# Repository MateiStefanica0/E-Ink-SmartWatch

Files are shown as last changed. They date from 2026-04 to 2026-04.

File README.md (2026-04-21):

## 1. Schema bloc

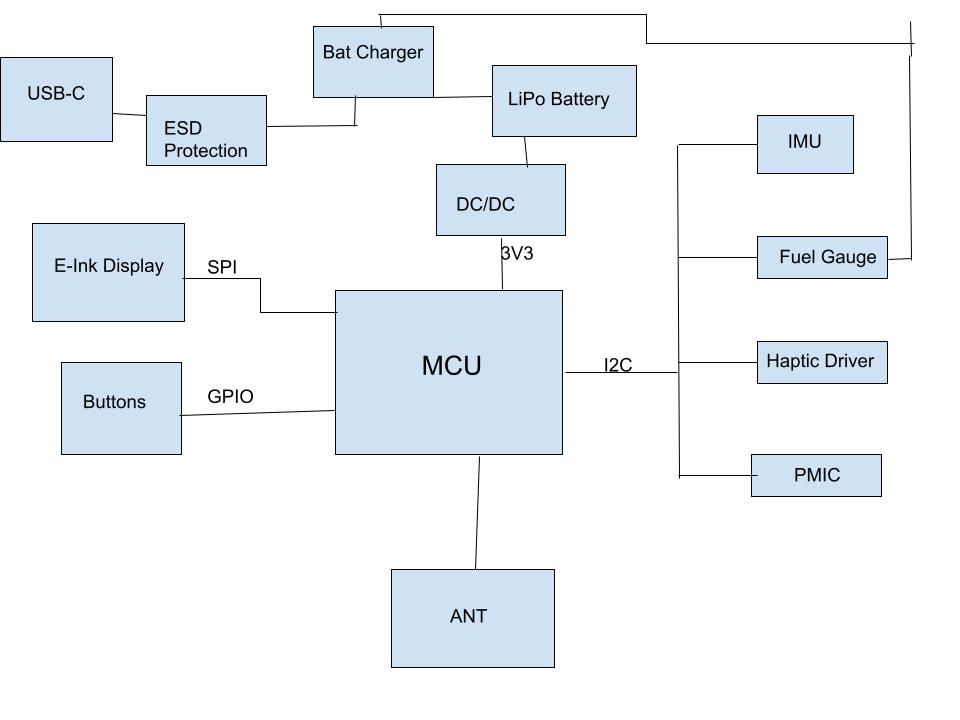
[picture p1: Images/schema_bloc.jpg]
Schema Bloc


## 2. Descrierea functionalitatii hardware

Sistemul este proiectat in jurul microcontrolerului nRF52840, punand accent pe conectivitate stabila si conservarea energiei, utilizand o tehnologie de afisare E-Paper care permite vizibilitate excelenta in lumina solara cu un consum de curent extrem de mic in starea statica.

### 2.1. Nucleul Sistemului (MCU)
* **Microcontroler:** Nordic nRF52840.
* **Comunicatie:** Gestioneaza functionalitatile Bluetooth si perifericele prin I2C si SPI.
* **Radio:** Semnalul trece printr-o retea de filtrare catre o antena ceramica de 2.4GHz. Sub antena, PCB-ul este decupat pentru a nu bloca semnalul.

### 2.2. Management Energie
* **Incarcare:** Chip-ul BQ25180 gestioneaza incarcarea bateriei LiPo prin mufa USB-C.
* **Monitorizare:** MAX17048 masoara constant nivelul bateriei si transmite datele prin I2C.
* **Regulator:** RT6160A (Buck-Boost) asigura o tensiune constanta de 3.3V, chiar si cand bateria se descarca.

### 2.3. Afisaj si Feedback
* **Ecran E-Paper:** Conectat prin interfata SPI pentru consum minim (consuma energie doar cand schimba imaginea).
* **Circuit Drive:** Include tranzistori si diode pentru a genera tensiunile necesare refresh-ului ecranului.
* **Vibratii:** Driver-ul DRV2605 controleaza motorul haptic, oferind alerte tactile utilizatorului.

### 2.4. Senzori si Protectie
* **Miscare:** Senzorul BMA423 (IMU) este folosit pentru pedometru si detectarea gestului de ridicare a mainii.
* **Protectie USB:** Chip-ul USBLC6-2 protejeaza placa impotriva descarcarilor electrostatice de pe portul USB.

### 2.5. Calcule de consum (estimativ)
* **Sleep Mode:** Consumul sistemului este de aproximativ 2-5 uA (nRF52840 + IMU in low power).
I_sleep = MCU_off + IMU_low + FuelGauge + DC/DC = 1.5 + 7 + 23 + 2 = ~33.5 uA
* **Active Mode:** In timpul transferului de date sau refresh-ului ecranului, consumul poate urca la 5-12 mA.
I_active = MCU_active + IMU_active + EPD_refresh + Haptic = ~10mAh
* **Autonomie:** 
Presupunand ca dintr-o ora, ceasul e activ 2 minute si in standby 58 de minute:
I_mediu = ( (I_active * 2 min) + (I_sleep * 58 min)) / 60 min = ~365 uA

Deci, autonomia e capacitatea_bateriei / I_mediu = 100mAh / 365uA = ~274 ore

## 3. Alocarea Pinilor nRF52840 (Pin Mapping)

Configuratia pinilor a fost aleasa pentru a optimiza rutarea pe PCB si pentru a respecta cerintele perifericelor. Toti pinii sunt configurati in firmware conform tabelului:

| Functie / Periferic | Semnal (Net) | Pin MCU | Explicatie |
| :--- | :--- | :--- | :--- |
| **I2C Bus (SCL)** | `I2C_SCL` | **P0.27** | Bus comun: IMU, Fuel Gauge, Haptic, PMIC. |
| **I2C Bus (SDA)** | `I2C_SDA` | **P0.26** | Bus comun: IMU, Fuel Gauge, Haptic, PMIC. |
| **SPI (SCK)** | `EPD_SCK` | **P0.31** | Ceas pentru transfer date catre ecran. |
| **SPI (MOSI)** | `EPD_MOSI` | **P0.29** | Date imagini catre ecran. |
| **EPD Control** | `EPD_BUSY` | **P0.05** | Indica daca ecranul este ocupat. |
| **EPD Control** | `EPD_RST` | **P0.06** | Reset hardware pentru ecran. |
| **EPD Control** | `EPD_DC` | **P0.08** | Selectie Date sau Comenzi (Data/Command). |
| **Butoane** | `SW_UP` | **P0.11** | Buton SUS (navigare). |
| **Butoane** | `SW_ENT` | **P0.12** | Buton SELECT (confirmare). |
| **Butoane** | `SW_DN` | **P0.14** | Buton JOS (navigare). |
| **Haptic Feedback**| `EN_HAPTIC` | **P0.17** | Activare driver vibratii. |
| **Senzor IMU** | `IMU_INT1` | **P0.19** | Intrerupere pentru detectare miscare. |
| **Debug/Prog** | `SWDIO` | `SWDIO` | Programare si depanare. |
| **Debug/Prog** | `SWCLK` | `SWCLK` | Ceas programare. |

---

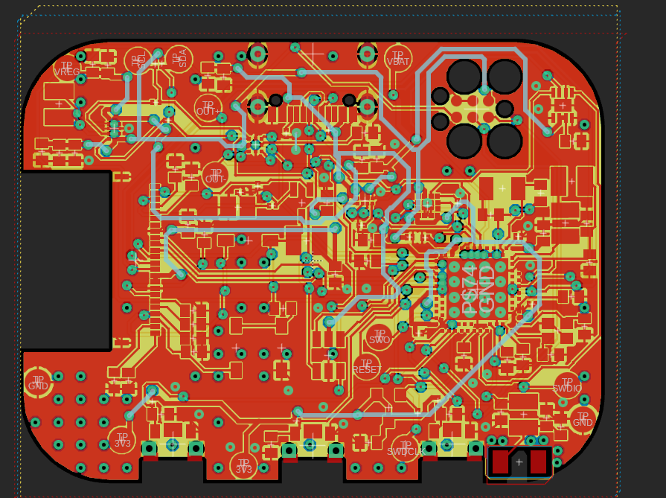
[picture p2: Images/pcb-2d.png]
PCB 2D

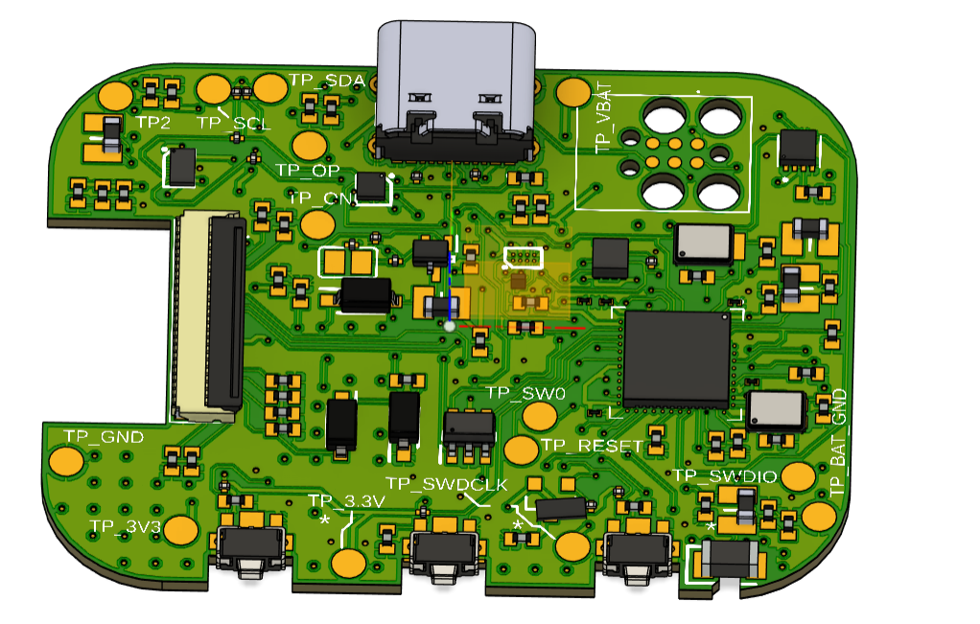
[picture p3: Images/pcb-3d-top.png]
PCB 3D-top

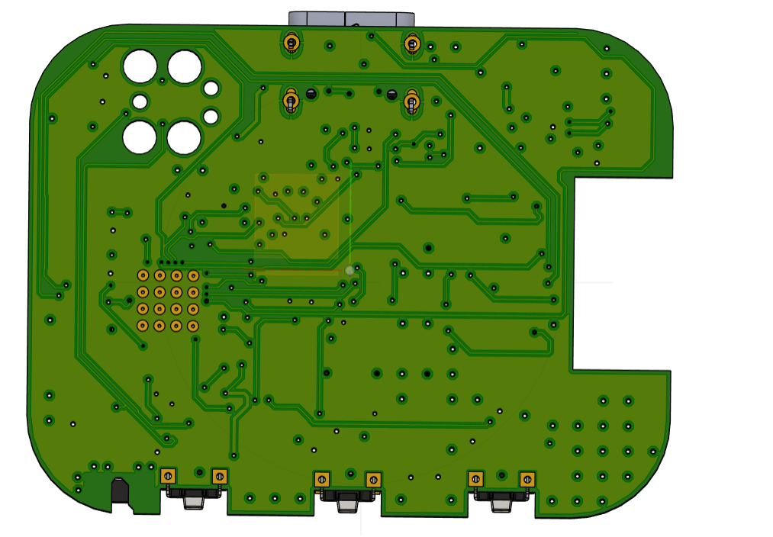
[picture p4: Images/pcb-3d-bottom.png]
PCB 3D-bottom

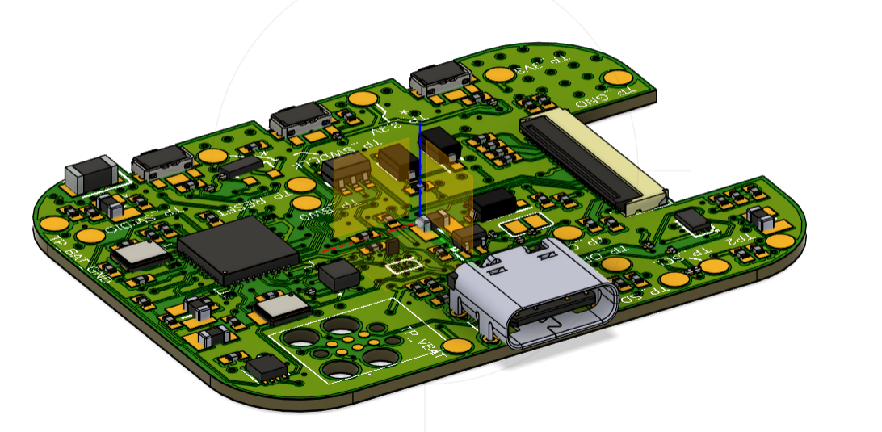
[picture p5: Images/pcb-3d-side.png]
PCB 3D-side

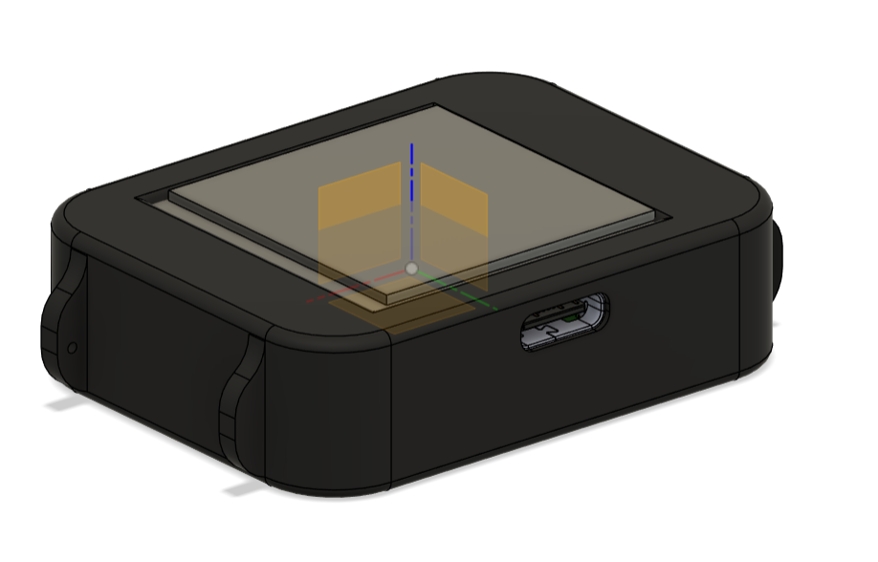
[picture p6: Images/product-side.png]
Carcasa-side

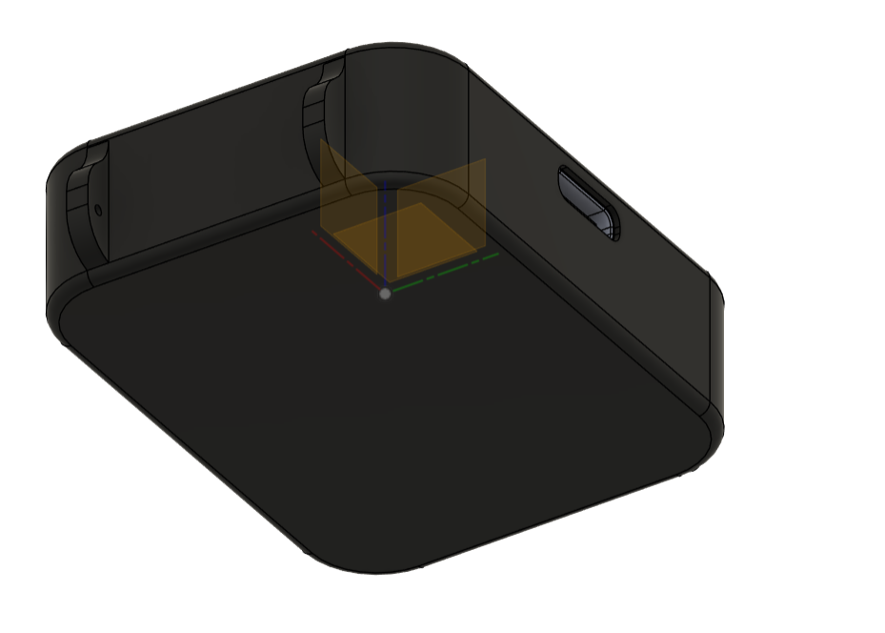
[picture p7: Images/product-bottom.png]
Carcasa-bottom


## 4. Detalii de Design (Design Log)

### 4.1. Implementare PCB
* **Antena RF:** Plasata pe margine, cu zona de sub ea libera (fara cupru) pentru semnal Bluetooth bun.
* **Grosime:** PCB-ul are 1.0mm grosime pentru a incapea in carcasa InkTime si am ales ca rutarea sa fie pe 4 layere: unul de GND, unul de Power, unul de top si unul de bottom.
* **Filtrare:** Condensatorii de 100nF sunt pusi cat mai aproape de pinii de alimentare ai chip-urilor.
* **Trasee:** Puterea are latime de 0.3mm, iar semnalele de date 0.15mm.
* **Abordare:** Initial, am incercat sa fac autorutare, dar nu a functionat, asa ca apoi am aranjat componentele pe placa pentru a fi cat mai putine fire intre pini indepartati, apoi am rutat semnalele care nu sunt de putere, apoi pe cele de putere, iar la final am pus polygon pour si am tras si ultimele fire de GND ramase.

### 4.2. Carcasa si Erori
* **Aliniere:** Butoanele si mufa USB-C sunt puse exact unde sunt gaurile in carcasa data.
* **Erori permise:** Erorile de tip "Dimension" de la USB si butoane sunt ignorate conform cerintelor proiectului. 
* **Erori ERC:** Singurele erori care au ramas sunt cele legate de pinii de care nu am legat nimic.
* **Erori DRC:** Erorile pe care le-am admis sunt cele cauzate de fire care trec printre alti pini ai microcontrollerului (asta nu se poate evita) sau viasuri care sunt prea apropiate din acelasi motiv.

## 5. Tabel BOM (Bill of Materials)

Mai jos sunt prezentate componentele principale necesare pentru asamblarea ceasului InkTime. Codurile de produs sunt optimizate pentru serviciul de asamblare JLC PCB.

| Designator | Componenta | Descriere / Parametri | Link Achizitie | Datasheet |
| :--- | :--- | :--- | :--- | :--- |
| U1 | **nRF52840** | MCU Bluetooth 5.4, ARM Cortex-M4F | [Link JLC](https://jlcpcb.com/partdetail/NordicSemicon-NRF52840_QIAAR/C190794) | [Datasheet](https://www.lcsc.com/datasheet/lcsc_datasheet_2304140030_Nordic-Semicon-NRF52840-QIAA-R_C190794.pdf) |
| U2 | **BQ25180YBGR** | IC Incarcare Baterie LiPo (I2C) | [Link JLC](https://jlcpcb.com/partdetail/TexasInstruments-BQ25180YBGR/C3682423) | [Datasheet](https://www.ti.com/cn/lit/gpn/bq25180) |
| U3 | **MAX17048G+T10**| Fuel Gauge (Monitorizare baterie) | [Link JLC](https://jlcpcb.com/partdetail/2777647-MAX17048GT10/C2682616) | [Datasheet](https://www.lcsc.com/datasheet/lcsc_datasheet_2410121738_Analog-Devices-Inc--Maxim-Integrated-MAX17048G-T10_C2682616.pdf) |
| IC1 | **RT6160AWSC** | Regulator Buck-Boost 3.3V | [Link JLC](https://jlcpcb.com/partdetail/RichtekTech-RT6160AWSC/C7065276) | [Datasheet](https://wmsc.lcsc.com/wmsc/upload/file/pdf/v2/lcsc/2312271436_Richtek-Tech-RT6160AWSC_C7065276.pdf) |
| IC2 | **BMA423** | Accelerometru 3 axe (IMU) | [Link JLC](https://jlcpcb.com/partdetail/BoschSensortec-BMA423/C189517) | [Datasheet](https://www.lcsc.com/datasheet/lcsc_datasheet_1810010040_Bosch-Sensortec-BMA423_C189517.pdf) |
| IC3 | **DRV2605YZFR** | Driver Motor Haptic (LRA/ERM) | [Link JLC](https://jlcpcb.com/partdetail/TexasInstruments-DRV2605YZFR/C81079) | [Datasheet](https://jlcpcb.com/partdetail/TexasInstruments-DRV2605YZFR/C81079) |
| ANT1 | **2450AT18B100E**| Antena Ceramica 2.4GHz | [Link JLC](https://jlcpcb.com/partdetail/JohansonDielectrics-2450AT18B100E/C2917717) | [Datasheet](https://www.lcsc.com/datasheet/lcsc_datasheet_2404021210_Johanson-Dielectrics-2450AT18B100E_C2917717.pdf) |
| J1 | **KH-TYPE-C-16P** | Conector USB Type-C 16 pini | [Link JLC](https://jlcpcb.com/partdetail/Shenzhen_KinghelmElec-KH_TYPE_C16P/C709357) | [Datasheet](https://jlcpcb.com/partdetail/Shenzhen_KinghelmElec-KH_TYPE_C16P/C709357) |
| J2 | **503480-2400** | Conector FPC 24 pini (E-Paper) | [Link JLC](https://jlcpcb.com/parts/componentSearch?searchTxt=503480-2400) | [Datasheet](https://www.molex.com/content/dam/molex/molex-dot-com/products/automated/en-us/salesdrawingpdf/503/503480/5034802400_sd.pdf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) |
| C_dec | **Condensator 100nF** | 0201, X5R, 6.3V (Decuplare generala) | [Link JLC](https://jlcpcb.com/partdetail/SamsungElectroMechanics-CL03A104KQ3NNNC/C1613) | [Datasheet](https://datasheet.lcsc.com/lcsc/1811141213_Samsung-Electro-Mechanics-CL03A104KQ3NNNC_C1613.pdf) |
| C_bulk | **Condensator 10uF** | 0402, X5R, 10V (Filtrare alimentare) | [Link JLC](https://jlcpcb.com/partdetail/MurataElectronics-GRM155R61A106ME11D/C155255) | [Datasheet](https://datasheet.lcsc.com/lcsc/1811011516_Murata-Electronics-GRM155R61A106ME11D_C155255.pdf) |
| R_pu | **Rezistenta 4.7k** | 0201, 1/20W (Pull-up I2C/Butoane) | [Link JLC](https://jlcpcb.com/partdetail/Yageo-RC0201JR074K7L/C13032) | [Datasheet](https://datasheet.lcsc.com/lcsc/1811021213_Yageo-RC0201JR-074K7L_C13032.pdf) |
| L_pwr | **Inductor 1.0uH** | 0805, 2.1A (Pentru RT6160A/Buck-Boost) | [Link JLC](https://jlcpcb.com/partdetail/Sunlord-MWSA0503S1R0MT/C2915000) | [Datasheet](https://datasheet.lcsc.com/lcsc/2203151500_Sunlord-MWSA0503S-1R0MT_C2915000.pdf) |
| X_32k | **Cristal 32.768kHz** | 1.6x1.0mm, 9pF (Pentru Sleep Mode nRF) | [Link JLC](https://jlcpcb.com/partdetail/YangzhouYangjieElectronic-FC1610AN32_7680KA_A/C147814) | [Datasheet](https://datasheet.lcsc.com/lcsc/1811141221_Epson-FC-1610-32-7680KA-A3_C147814.pdf) |
| D_esd | **USBLC6-2P6** | Protectie ESD USB (SOT-666) | [Link JLC](https://jlcpcb.com/partdetail/STMicroelectronics-USBLC62P6/C7519) | [Datasheet](https://www.st.com/resource/en/datasheet/usblc6-2.pdf) |

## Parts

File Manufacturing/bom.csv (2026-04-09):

Qty | Value | Device | Package | Parts | Description | ARROW_PART_NUMBER | ARROW_PRICE-STOCK | AVAILABILITY | CHECK_PRICES | COPYRIGHT | DESCRIPTION | DIGI-KEY_PART_NUMBER_1 | DIGI-KEY_PART_NUMBER_2 | DIGI-KEY_PART_NUMBER_3 | HEIGHT | JLCPCB | MANUFACTURER_NAME | MANUFACTURER_PART_NUMBER | MF | MOUSER_PART_NUMBER | MOUSER_PRICE-STOCK | MP | PACKAGE | POPULARITY | PRICE | PROD_ID | PURCHASE-URL | SNAPEDA_LINK | SPICEMODEL | SPICEPREFIX | TP_SIGNAL_NAME | VALUE
3 | 0 | ERA-1AEB3401C_CPF0201D7K68C1 | ERA-1AEB3401C_0201 | R2, R3, R4 | 7.68k 0201 Thin Film Surface Mount Fixed Resistor +/-0.5% 0.031W CPF0201D7K68C1
4 | 0.1uF | ESP32_C6_LIBRARY_1_ESP32_WROVER_EAGLE-LTSPICE_CC0402 | ESP32_C6_LIBRARY_1_ESP32_WROVER_EAGLE-LTSPICE_C0402 | C23, C27, C34, C42 | CAPACITOR, European symbol |  |  |  |  |  |  |  |  |  |  |  |  |  |  |  |  |  |  |  |  |  |  |  | NONE | C
1 | 0.1uF/50V | ESP32_C6_LIBRARY_1_ESP32_WROVER_EAGLE-LTSPICE_CC0402 | ESP32_C6_LIBRARY_1_ESP32_WROVER_EAGLE-LTSPICE_C0402 | EPD_C5 | CAPACITOR, European symbol |  |  |  |  |  |  |  |  |  |  |  |  |  |  |  |  |  |  |  |  |  |  |  | NONE | C
1 | 0.47 | ERA-1AEB3401C_CPF0201D7K68C1 | ERA-1AEB3401C_0201 | R1_EP_DR | 7.68k 0201 Thin Film Surface Mount Fixed Resistor +/-0.5% 0.031W CPF0201D7K68C1
5 | 100nF | NORDIC_NRF_3_CAPACITOR_0201_L | NORDIC_NRF_3_RESC0201_L | C5, C7, C8, C12, C19 | Generic chip capacitor
1 | 100pF | ESP32_C6_LIBRARY_1_ESP32_WROVER_EAGLE-LTSPICE_CC0402 | ESP32_C6_LIBRARY_1_ESP32_WROVER_EAGLE-LTSPICE_C0402 | C11 | CAPACITOR, European symbol |  |  |  |  |  |  |  |  |  |  |  |  |  |  |  |  |  |  |  |  |  |  |  | NONE | C
1 | 10K | ERA-1AEB3401C_CPF0201D7K68C1 | ERA-1AEB3401C_0201 | R2_EP_DR | 7.68k 0201 Thin Film Surface Mount Fixed Resistor +/-0.5% 0.031W CPF0201D7K68C1
1 | 10k | CPF0201D7K68C1_CPF0201D7K68C1 | CPF0201D7K68C1_0201 | R9 | 7.68k 0201 Thin Film Surface Mount Fixed Resistor +/-0.5% 0.031W CPF0201D7K68C1
4 | 10k | ERA-1AEB3401C_CPF0201D7K68C1 | ERA-1AEB3401C_0201 | R1, R5, R6, R_PWR_EPD | 7.68k 0201 Thin Film Surface Mount Fixed Resistor +/-0.5% 0.031W CPF0201D7K68C1
1 | 10nH | MLP2016SR47MT0S1_FTC252012SR47MBCA | MLP2016SR47MT0S1_INDC2016X100N | L3 | SMD / SMT Inductors (Coils), L=0.47?H, L x W x T : |  |  |  |  |  | SMD / SMT Inductors (Coils) | L=0.47?H | L x W x T : |  |  |  | 1mm | https://jlcpcb.com/partdetail/6763488-FTC252012SR47MBCA/C5832368 | TDK | FTC252012SR47MBCA
3 | 10uF | ESP32_C6_LIBRARY_1_ESP32_WROVER_EAGLE-LTSPICE_CC0402 | ESP32_C6_LIBRARY_1_ESP32_WROVER_EAGLE-LTSPICE_C0402 | C1-EP-DR, C24, C39 | CAPACITOR, European symbol |  |  |  |  |  |  |  |  |  |  |  |  |  |  |  |  |  |  |  |  |  |  |  | NONE | C
1 | 10uH | MLP2016SR47MT0S1_FTC252012SR47MBCA | MLP2016SR47MT0S1_INDC2016X100N | L2 | SMD / SMT Inductors (Coils), L=0.47?H, L x W x T : |  |  |  |  |  | SMD / SMT Inductors (Coils) | L=0.47?H | L x W x T : |  |  |  | 1mm | https://jlcpcb.com/partdetail/6763488-FTC252012SR47MBCA/C5832368 | TDK | FTC252012SR47MBCA
4 | 12pF | ESP32_C6_LIBRARY_1_ESP32_WROVER_EAGLE-LTSPICE_CC0402 | ESP32_C6_LIBRARY_1_ESP32_WROVER_EAGLE-LTSPICE_C0402 | C1, C2, C17, C18 | CAPACITOR, European symbol |  |  |  |  |  |  |  |  |  |  |  |  |  |  |  |  |  |  |  |  |  |  |  | NONE | C
2 | 1pF | ESP32_C6_LIBRARY_1_ESP32_WROVER_EAGLE-LTSPICE_CC0402 | ESP32_C6_LIBRARY_1_ESP32_WROVER_EAGLE-LTSPICE_C0402 | C3, C4 | CAPACITOR, European symbol |  |  |  |  |  |  |  |  |  |  |  |  |  |  |  |  |  |  |  |  |  |  |  | NONE | C
7 | 1uF | ESP32_C6_LIBRARY_1_ESP32_WROVER_EAGLE-LTSPICE_CC0402 | ESP32_C6_LIBRARY_1_ESP32_WROVER_EAGLE-LTSPICE_C0402 | C15, C29, C30, C31, C32, C37, C38 | CAPACITOR, European symbol |  |  |  |  |  |  |  |  |  |  |  |  |  |  |  |  |  |  |  |  |  |  |  | NONE | C
8 | 1uF/50V | ESP32_C6_LIBRARY_1_ESP32_WROVER_EAGLE-LTSPICE_CC0402 | ESP32_C6_LIBRARY_1_ESP32_WROVER_EAGLE-LTSPICE_C0402 | EPD_C2, EPD_C6, EPD_C7, EPD_C8, EPD_C9, EPD_C10, EPD_C11, EPD_C12 | CAPACITOR, European symbol |  |  |  |  |  |  |  |  |  |  |  |  |  |  |  |  |  |  |  |  |  |  |  | NONE | C
1 | 2.2 | ERA-1AEB3401C_CPF0201D7K68C1 | ERA-1AEB3401C_0201 | R_TYPE_SEL | 7.68k 0201 Thin Film Surface Mount Fixed Resistor +/-0.5% 0.031W CPF0201D7K68C1
3 | 2025-10-22_07-23-44_LIBRARY_EVP-AKE31ASW_EVP-AKE31A_PAN | 2025-10-22_07-23-44_LIBRARY_EVP-AKE31ASW_EVP-AKE31A_PAN | 2025-10-22_07-23-44_LIBRARY_SW_EVP-AKE31A_PAN | SW1, SW2, SW3 |  |  |  |  |  | Copyright (C) 2025 Ultra Librarian. All rights reserved. |  | P123437TR-ND | P123437CT-ND | P123437DKR-ND |  |  | Panasonic | EVP-AKE31A
1 | 20V/4.2A/52mO/1.4W | ESP32_C6_LIBRARY_4_ESP32_WROVER_SPARKFUN-DISCRETESEMI_MOSFET_PCH-DMG2305UX-7 | ESP32_C6_LIBRARY_4_ESP32_C6_LIBRARY_4_ESP32_C6_LIBRARY_4_ESP32_C6_LIBRARY_4_ESP32_WROVER_SPARKFUN-DISCRETESEMI_SOT23-3 | Q1 | P-channel MOSFETs |  |  |  |  |  |  |  |  |  |  |  |  |  |  |  |  |  |  |  |  | TRAN-14388 |  |  |  |  |  | 20V/4.2A/52mO/1.4W
2 | 22uF | ESP32_C6_LIBRARY_1_ESP32_WROVER_EAGLE-LTSPICE_CC0402 | ESP32_C6_LIBRARY_1_ESP32_WROVER_EAGLE-LTSPICE_C0402 | C25, C33 | CAPACITOR, European symbol |  |  |  |  |  |  |  |  |  |  |  |  |  |  |  |  |  |  |  |  |  |  |  | NONE | C
1 | 2450AT18B100E_2450AT18B100E | 2450AT18B100E_2450AT18B100E | 2450AT18B100E_ANTC3216X140N | ANT1 | Antennas 2.45GHz ANTENNA | 2450AT18B100E | https://www.arrow.com/en/products/2450at18b100e/johanson-dielectrics?utm_currency=USD&region=nac |  |  |  | Antennas 2.45GHz ANTENNA |  |  |  | 1.4mm |  | JOHANSON TECHNOLOGY | 2450AT18B100E |  | 609-2450AT18B100E | https://www.mouser.co.uk/ProductDetail/Johanson-Technology/2450AT18B100E?qs=yCnrNFeXz%252Bh5MFsFIXGZGA%3D%3D
1 | 3.9nH | MLP2016SR47MT0S1_FTC252012SR47MBCA | MLP2016SR47MT0S1_INDC2016X100N | L1 | SMD / SMT Inductors (Coils), L=0.47?H, L x W x T : |  |  |  |  |  | SMD / SMT Inductors (Coils) | L=0.47?H | L x W x T : |  |  |  | 1mm | https://jlcpcb.com/partdetail/6763488-FTC252012SR47MBCA/C5832368 | TDK | FTC252012SR47MBCA
1 | 32.768kHz | NORDIC_NRF_1_XTAL_32KHZ | NORDIC_NRF_1_XTAL_3215_N | X2
1 | 32MHz | NORDIC_NRF_XTAL_32MHZ | NORDIC_NRF_BT-XTAL_2016_N | X1
2 | 3k3 | ERA-1AEB3401C_CPF0201D7K68C1 | ERA-1AEB3401C_0201 | R17, R18 | 7.68k 0201 Thin Film Surface Mount Fixed Resistor +/-0.5% 0.031W CPF0201D7K68C1
5 | 4.7uF | ESP32_C6_LIBRARY_1_ESP32_WROVER_EAGLE-LTSPICE_CC0402 | ESP32_C6_LIBRARY_1_ESP32_WROVER_EAGLE-LTSPICE_C0402 | C6, C14, C20, C21, C43 | CAPACITOR, European symbol |  |  |  |  |  |  |  |  |  |  |  |  |  |  |  |  |  |  |  |  |  |  |  | NONE | C
1 | 4.7uF/25V | ESP32_C6_LIBRARY_1_ESP32_WROVER_EAGLE-LTSPICE_CC0402 | ESP32_C6_LIBRARY_1_ESP32_WROVER_EAGLE-LTSPICE_C0402 | C2-EP-DR | CAPACITOR, European symbol |  |  |  |  |  |  |  |  |  |  |  |  |  |  |  |  |  |  |  |  |  |  |  | NONE | C
1 | 47nF | ESP32_C6_LIBRARY_1_ESP32_WROVER_EAGLE-LTSPICE_CC0402 | ESP32_C6_LIBRARY_1_ESP32_WROVER_EAGLE-LTSPICE_C0402 | C16 | CAPACITOR, European symbol |  |  |  |  |  |  |  |  |  |  |  |  |  |  |  |  |  |  |  |  |  |  |  | NONE | C
1 | 503480-2400_503480-2400 | 503480-2400_503480-2400 | 503480-2400_5034802400 | J2 | FFC & FPC Connectors 0.5mm FPC RA SMT Dual Contact 24Ckt |  |  |  |  |  | FFC & FPC Connectors 0.5mm FPC RA SMT Dual Contact 24Ckt |  |  |  | 1.87mm |  | Molex | 503480-2400 |  | 538-503480-2400 | https://www.mouser.co.uk/ProductDetail/Molex/503480-2400?qs=OAhjpuo3Vu7efIoxFh9AOw%3D%3D
2 | 5k1 | ERA-1AEB3401C_CPF0201D7K68C1 | ERA-1AEB3401C_0201 | R1_USB, R2_USB | 7.68k 0201 Thin Film Surface Mount Fixed Resistor +/-0.5% 0.031W CPF0201D7K68C1
1 | 68uH | MLP2016SR47MT0S1_FTC252012SR47MBCA | MLP2016SR47MT0S1_INDC2016X100N | L5 | SMD / SMT Inductors (Coils), L=0.47?H, L x W x T : |  |  |  |  |  | SMD / SMT Inductors (Coils) | L=0.47?H | L x W x T : |  |  |  | 1mm | https://jlcpcb.com/partdetail/6763488-FTC252012SR47MBCA/C5832368 | TDK | FTC252012SR47MBCA
1 | 820pF | ESP32_C6_LIBRARY_1_ESP32_WROVER_EAGLE-LTSPICE_CC0402 | ESP32_C6_LIBRARY_1_ESP32_WROVER_EAGLE-LTSPICE_C0402 | C9 | CAPACITOR, European symbol |  |  |  |  |  |  |  |  |  |  |  |  |  |  |  |  |  |  |  |  |  |  |  | NONE | C
1 | BMA423_BMA423 | BMA423_BMA423 | BMA423_BMA423 | IC3 | Accelerometers Triaxial low-g 12bit Acceleration Sensor | BMA423 | https://www.arrow.com/en/products/bma423/bosch |  |  |  | Accelerometers Triaxial low-g 12bit Acceleration Sensor |  |  |  | 1mm |  | BOSCH | BMA423 |  | 262-BMA423 | https://www.mouser.co.uk/ProductDetail/Bosch-Sensortec/BMA423?qs=HXFqYaX1Q2xC%252BSgeGoX3mg%3D%3D
1 | BQ25180YBGR_BQ25180YBGR | BQ25180YBGR_BQ25180YBGR | BQ25180YBGR_BGA8C40P2X4_100X155X50 | IC1 | Charger IC Lithium Ion/Polymer, Lithium Iron Phosphate 8-DSBGA (1.6x1.1) | BQ25180YBGR | https://www.arrow.com/en/products/bq25180ybgr/texas-instruments?utm_currency=USD&region=nac |  |  |  | Charger IC Lithium Ion/Polymer | Lithium Iron Phosphate 8-DSBGA (1.6x1.1) |  |  |  | 0.5mm |  | Texas Instruments | BQ25180YBGR |  | 595-BQ25180YBGR | https://www.mouser.co.uk/ProductDetail/Texas-Instruments/BQ25180YBGR?qs=doiCPypUmgEWjAK%252BJAX6Tw%3D%3D
1 | DRV2605YZFR_DRV2605YZFR | DRV2605YZFR_DRV2605YZFR | DRV2605YZFR_BGA9C50P3X3_144X144X62 | IC4 | Haptic Driver for ERM/LRA with Built-In Library and Smart Loop Architecture | DRV2605YZFR | https://www.arrow.com/en/products/drv2605yzfr/texas-instruments?region=nac |  |  |  | Haptic Driver for ERM/LRA with Built-In Library and Smart Loop Architecture |  |  |  | 0.625mm |  | Texas Instruments | DRV2605YZFR
1 | ESP32_C6_LIBRARY_3_USBLC6-2SC6Y | ESP32_C6_LIBRARY_3_USBLC6-2SC6Y | ESP32_C6_LIBRARY_3_SOT95P280X145-6N | D1 | Low Cap. ESD Protection Auto SOT-23-6 STMicroelectronics USBLC6-2SC6Y, Dual Uni-Directional TVS Diode Array, 6-Pin SOT-23 |  |  | In Stock | https://www.snapeda.com/parts/USBLC6-2SC6Y/STMicroelectronics/view-part/?ref=eda |  | 17V Clamp 5A (8/20µs) Ipp Tvs Diode Surface Mount SOT-23-6 |  |  |  |  |  |  |  | STMicroelectronics |  |  | USBLC6-2SC6Y | SOT-23-6 STMicroelectronics |  | None |  |  | https://www.snapeda.com/parts/USBLC6-2SC6Y/STMicroelectronics/view-part/?ref=snap
1 | ESP32_C6_LIBRARY_6_SI1308EDL-T1-GE3 | ESP32_C6_LIBRARY_6_SI1308EDL-T1-GE3 | ESP32_C6_LIBRARY_6_SOT65P210X110-3N | Q3 | MOSFET N-Ch 30V 1.5A TrenchFET SC70 Vishay Si1308EDL-T1-GE3 N-channel MOSFET Transistor, 1.5 A, 30 V, 3-Pin SC-70 |  |  | In Stock | https://www.snapeda.com/parts/SI1308EDL-T1-GE3/Vishay+Siliconix/view-part/?ref=eda |  | Si1308EDL-T1-GE3 N-channel MOSFET Transistor | 1.5 A | 30 V | 3-Pin SC-70 | Siliconix / Vishay SI1308EDL-T1-GE3 |  |  |  |  |  |  |  | Vishay Siliconix |  |  | SI1308EDL-T1-GE3 | SOT-323 Vishay Semiconductor |  | None |  | https://www.snapeda.com/api/url_track_click_mouser/?unipart_id=274603&manufacturer=Vishay Siliconix&part_name=SI1308EDL-T1-GE3&search_term=None | https://www.snapeda.com/parts/SI1308EDL-T1-GE3/Vishay+Siliconix/view-part/?ref=snap
1 | ESP32_C6_LIBRARY_MAX17048G+T10 | ESP32_C6_LIBRARY_MAX17048G+T10 | ESP32_C6_LIBRARY_SON50P200X200X80-9N | U1 | Check availability |  |  | In Stock | https://www.snapeda.com/parts/MAX17048G+T10/Analog+Devices/view-part/?ref=eda |  | 3µA 1-Cell/2-Cell Fuel Gauge with ModelGauge |  |  |  |  |  |  |  | Analog Devices |  |  | MAX17048G+T10 | TDFN-8 Maxim |  | None |  | https://www.snapeda.com/api/url_track_click_mouser/?unipart_id=329239&manufacturer=Analog Devices&part_name=MAX17048G+T10&search_term=None | https://www.snapeda.com/parts/MAX17048G+T10/Analog+Devices/view-part/?ref=snap
14 | HECTOR_WATCH_1_TPTP20R | HECTOR_WATCH_1_TPTP20R | HECTOR_WATCH_1_TP20R | TP2, TP_3.3V, TP_3V3, TP_BAT_GND, TP_GND, TP_ON, TP_OP, TP_RESET, TP_SCL, TP_SDA, TP_SW0, TP_SWDCLK, TP_SWDIO, TP_VBAT | Test pad |  |  |  |  |  |  |  |  |  |  |  |  |  |  |  |  |  |  | 2
1 | KH-TYPE-C-16P_KH-TYPE-C-16P | KH-TYPE-C-16P_KH-TYPE-C-16P | KH-TYPE-C-16P_KINGHELM_KH-TYPE-C-16P | J3 | Check availability |  |  | Not in stock | https://www.snapeda.com/parts/KH-TYPE-C-16P/Kinghelm/view-part/?ref=eda |  |  |  |  |  |  |  |  |  | kinghelm |  |  | KH-TYPE-C-16P | None |  | None |  |  | https://www.snapeda.com/parts/KH-TYPE-C-16P/Kinghelm/view-part/?ref=snap
3 | MBR0503 | ESP32_C6_LIBRARY_5_MBR0530 | ESP32_C6_LIBRARY_5_SOD3716X135N | D2, D4, D5 | ON SEMICONDUCTOR - MBR0530 - DIODE, SCHOTTKY, 0.5A, 30V, SOD-123 |  |  | In Stock | https://www.snapeda.com/parts/MBR0530/Onsemi/view-part/?ref=eda |  | Diode Schottky 30 V 500mA Surface Mount SOD-123 |  |  |  |  |  |  |  | ON Semiconductor |  |  | MBR0530 | SOD-123-2 ON Semiconductor |  | None |  | https://www.snapeda.com/api/url_track_click_mouser/?unipart_id=179458&manufacturer=ON Semiconductor&part_name=MBR0530&search_term=None | https://www.snapeda.com/parts/MBR0530/Onsemi/view-part/?ref=snap
1 | MLP2016SR47MT0S1_FTC252012SR47MBCA | MLP2016SR47MT0S1_FTC252012SR47MBCA | MLP2016SR47MT0S1_INDC2016X100N | L7 | SMD / SMT Inductors (Coils), L=0.47?H, L x W x T : |  |  |  |  |  | SMD / SMT Inductors (Coils) | L=0.47?H | L x W x T : |  |  |  | 1mm | https://jlcpcb.com/partdetail/6763488-FTC252012SR47MBCA/C5832368 | TDK | FTC252012SR47MBCA
3 | N.C. | ESP32_C6_LIBRARY_1_ESP32_WROVER_EAGLE-LTSPICE_CC0402 | ESP32_C6_LIBRARY_1_ESP32_WROVER_EAGLE-LTSPICE_C0402 | C10, C13, C22 | CAPACITOR, European symbol |  |  |  |  |  |  |  |  |  |  |  |  |  |  |  |  |  |  |  |  |  |  |  | NONE | C
1 | NORDIC_NRF_4_NRF52840_QF | NORDIC_NRF_4_NRF52840_QF | NORDIC_NRF_4_AQFN50P700X700X85_HS-74N | U$1 | nRF52840
1 | RT6160AWSC_RT6160AWSC | RT6160AWSC_RT6160AWSC | RT6160AWSC_BGA15C40P3X5_140X230X60 | IC2 | Buck-Boost Regulator Positive Output Step-Up/Step-Down I2C DC-DC Controller IC 15-WL-CSP (BSC) (1.4x2.3) |  |  |  |  |  | Buck-Boost Regulator Positive Output Step-Up/Step-Down I2C DC-DC Controller IC 15-WL-CSP (BSC) (1.4x2.3) |  |  |  | 0.6mm |  | RICHTEK | RT6160AWSC |  | 835-RT6160AWSC | https://www.mouser.co.uk/ProductDetail/Richtek/RT6160AWSC?qs=amGC7iS6iy%2FLd9PSoixZXQ%3D%3D
1 | SJ | ESP32_C6_LIBRARY_7_JUMPER_SJ | ESP32_C6_LIBRARY_7_JUMPER_SJ | SJ1 | SMD solder JUMPER |  |  |  |  |  |  |  |  |  |  |  |  |  |  |  |  |  |  | 3
1 | TC2030-IDC_TC2030-IDC | TC2030-IDC_TC2030-IDC | TC2030-IDC_TC2030IDC | J1 | CABLE ADAPTER 6 POS |  |  |  |  |  | CABLE ADAPTER 6 POS |  |  |  | 19mm |  | Tag Connect | TC2030-IDC
1 | iuF/50V | ESP32_C6_LIBRARY_1_ESP32_WROVER_EAGLE-LTSPICE_CC0402 | ESP32_C6_LIBRARY_1_ESP32_WROVER_EAGLE-LTSPICE_C0402 | EPD_C1 | CAPACITOR, European symbol |  |  |  |  |  |  |  |  |  |  |  |  |  |  |  |  |  |  |  |  |  |  |  | NONE | C

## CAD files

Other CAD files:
Mechanical/proiect_tsc-pcb3D.f3z

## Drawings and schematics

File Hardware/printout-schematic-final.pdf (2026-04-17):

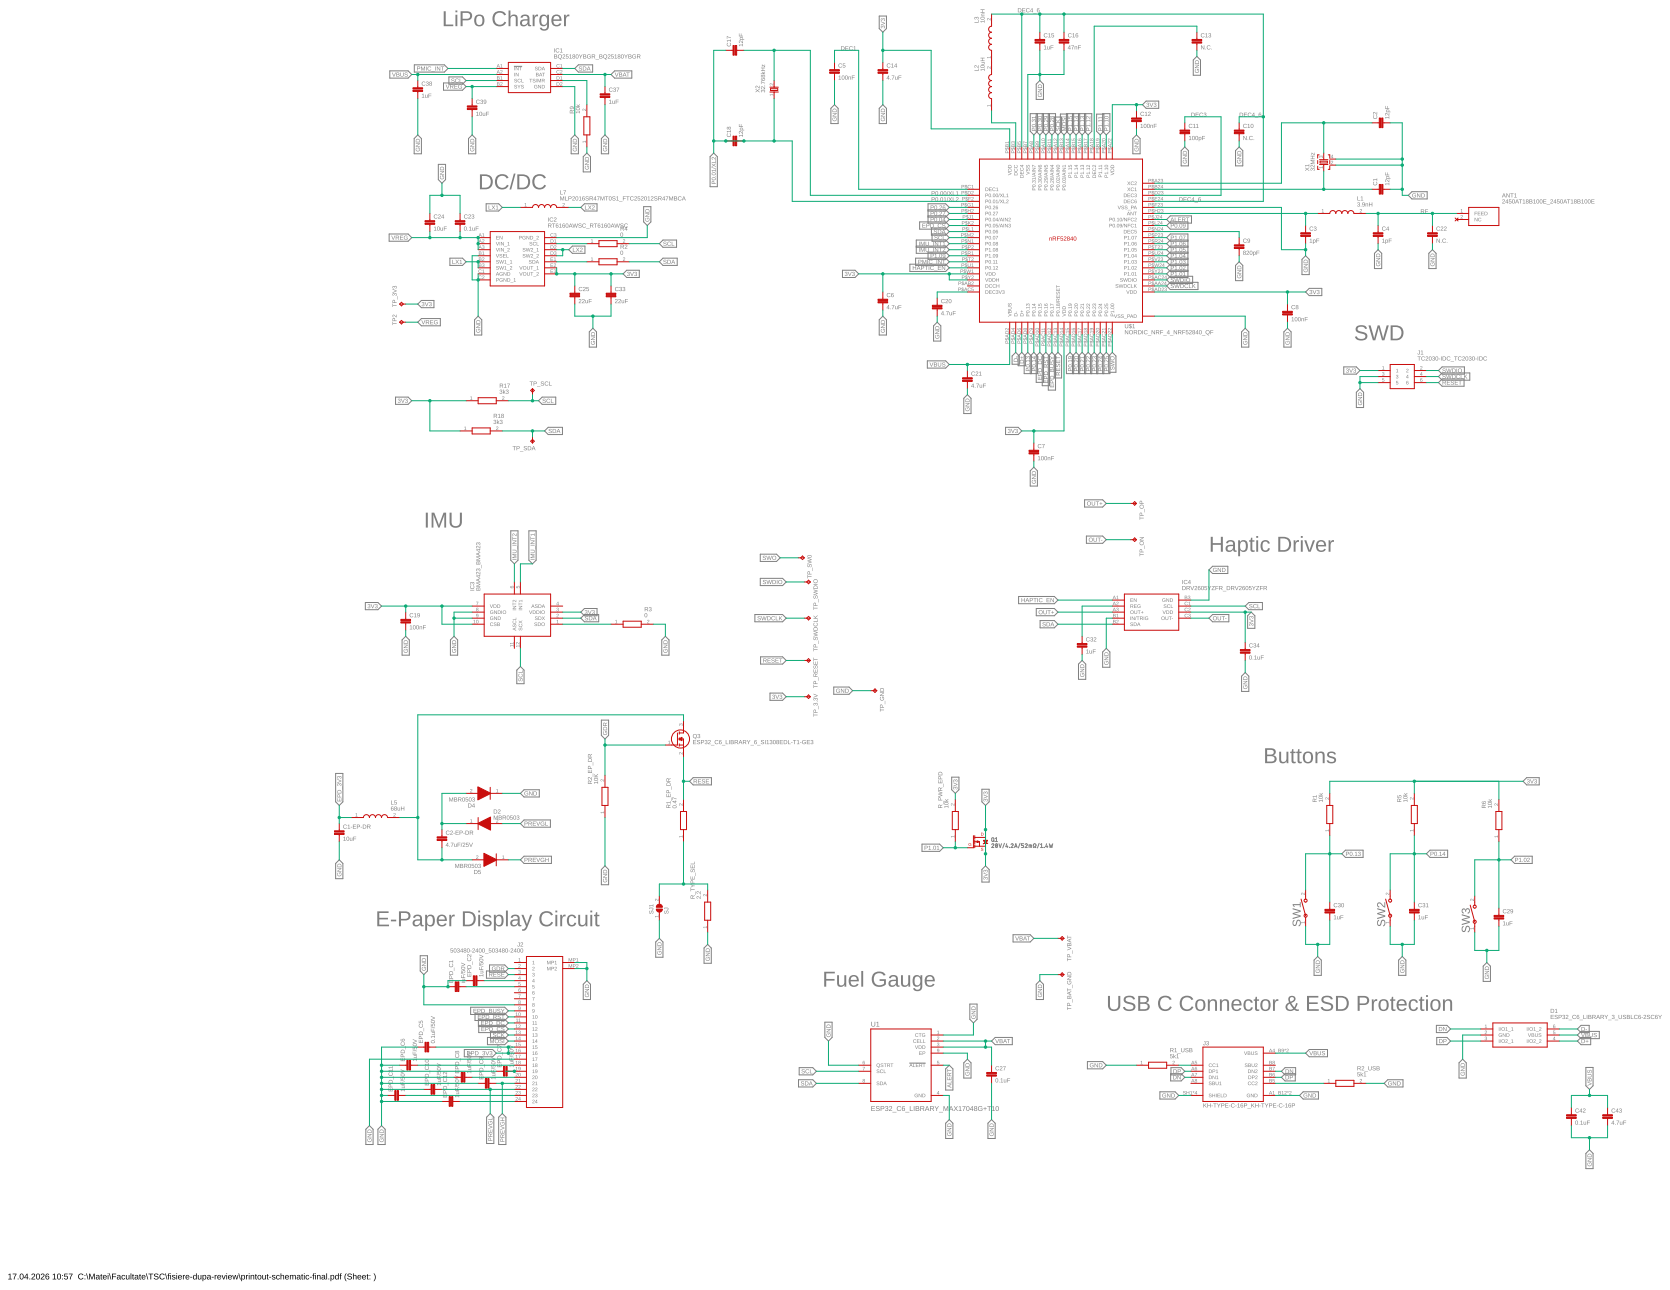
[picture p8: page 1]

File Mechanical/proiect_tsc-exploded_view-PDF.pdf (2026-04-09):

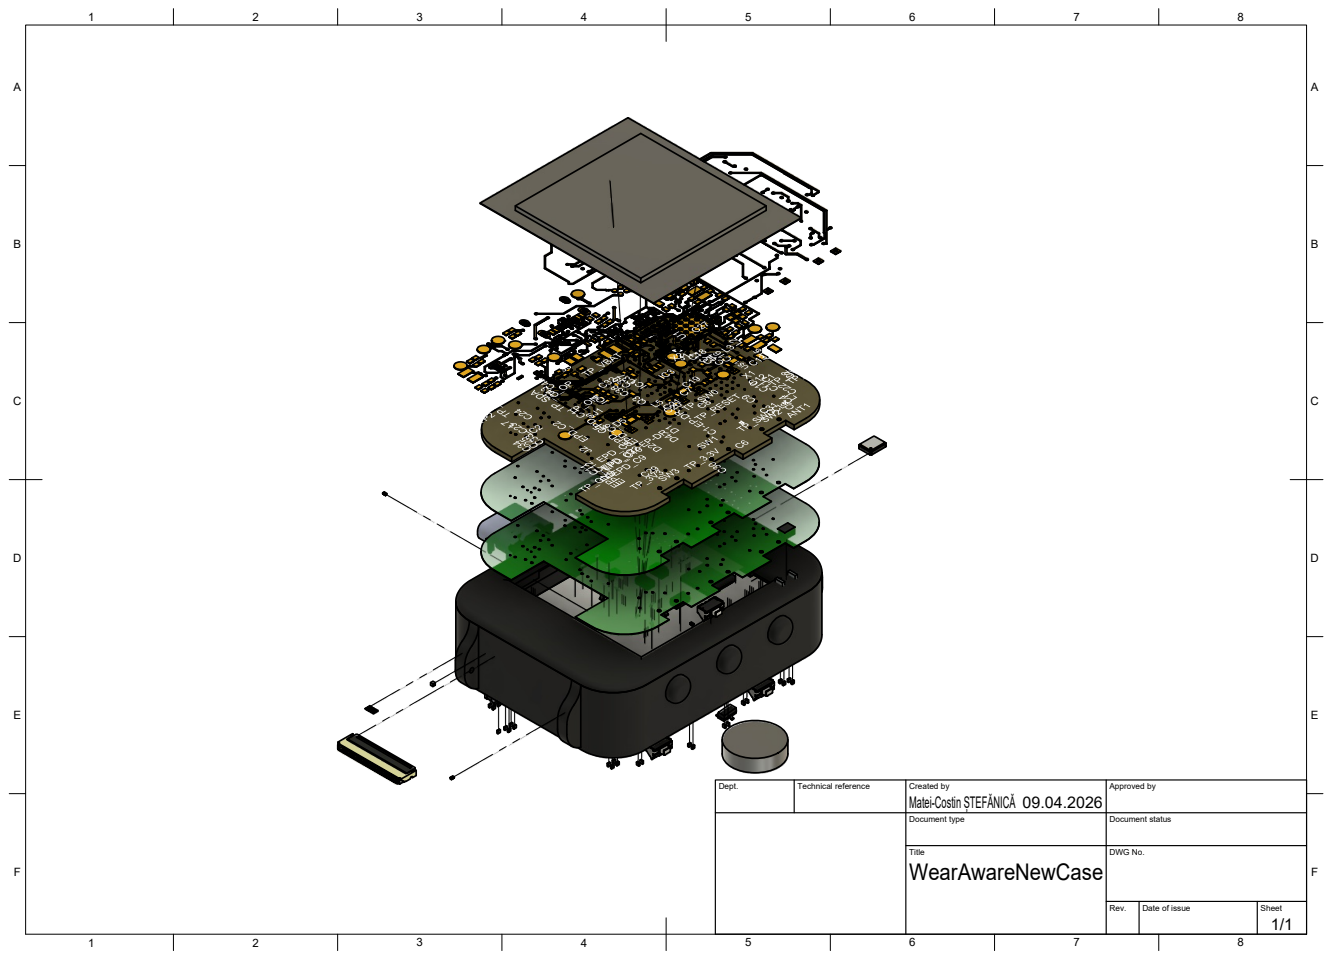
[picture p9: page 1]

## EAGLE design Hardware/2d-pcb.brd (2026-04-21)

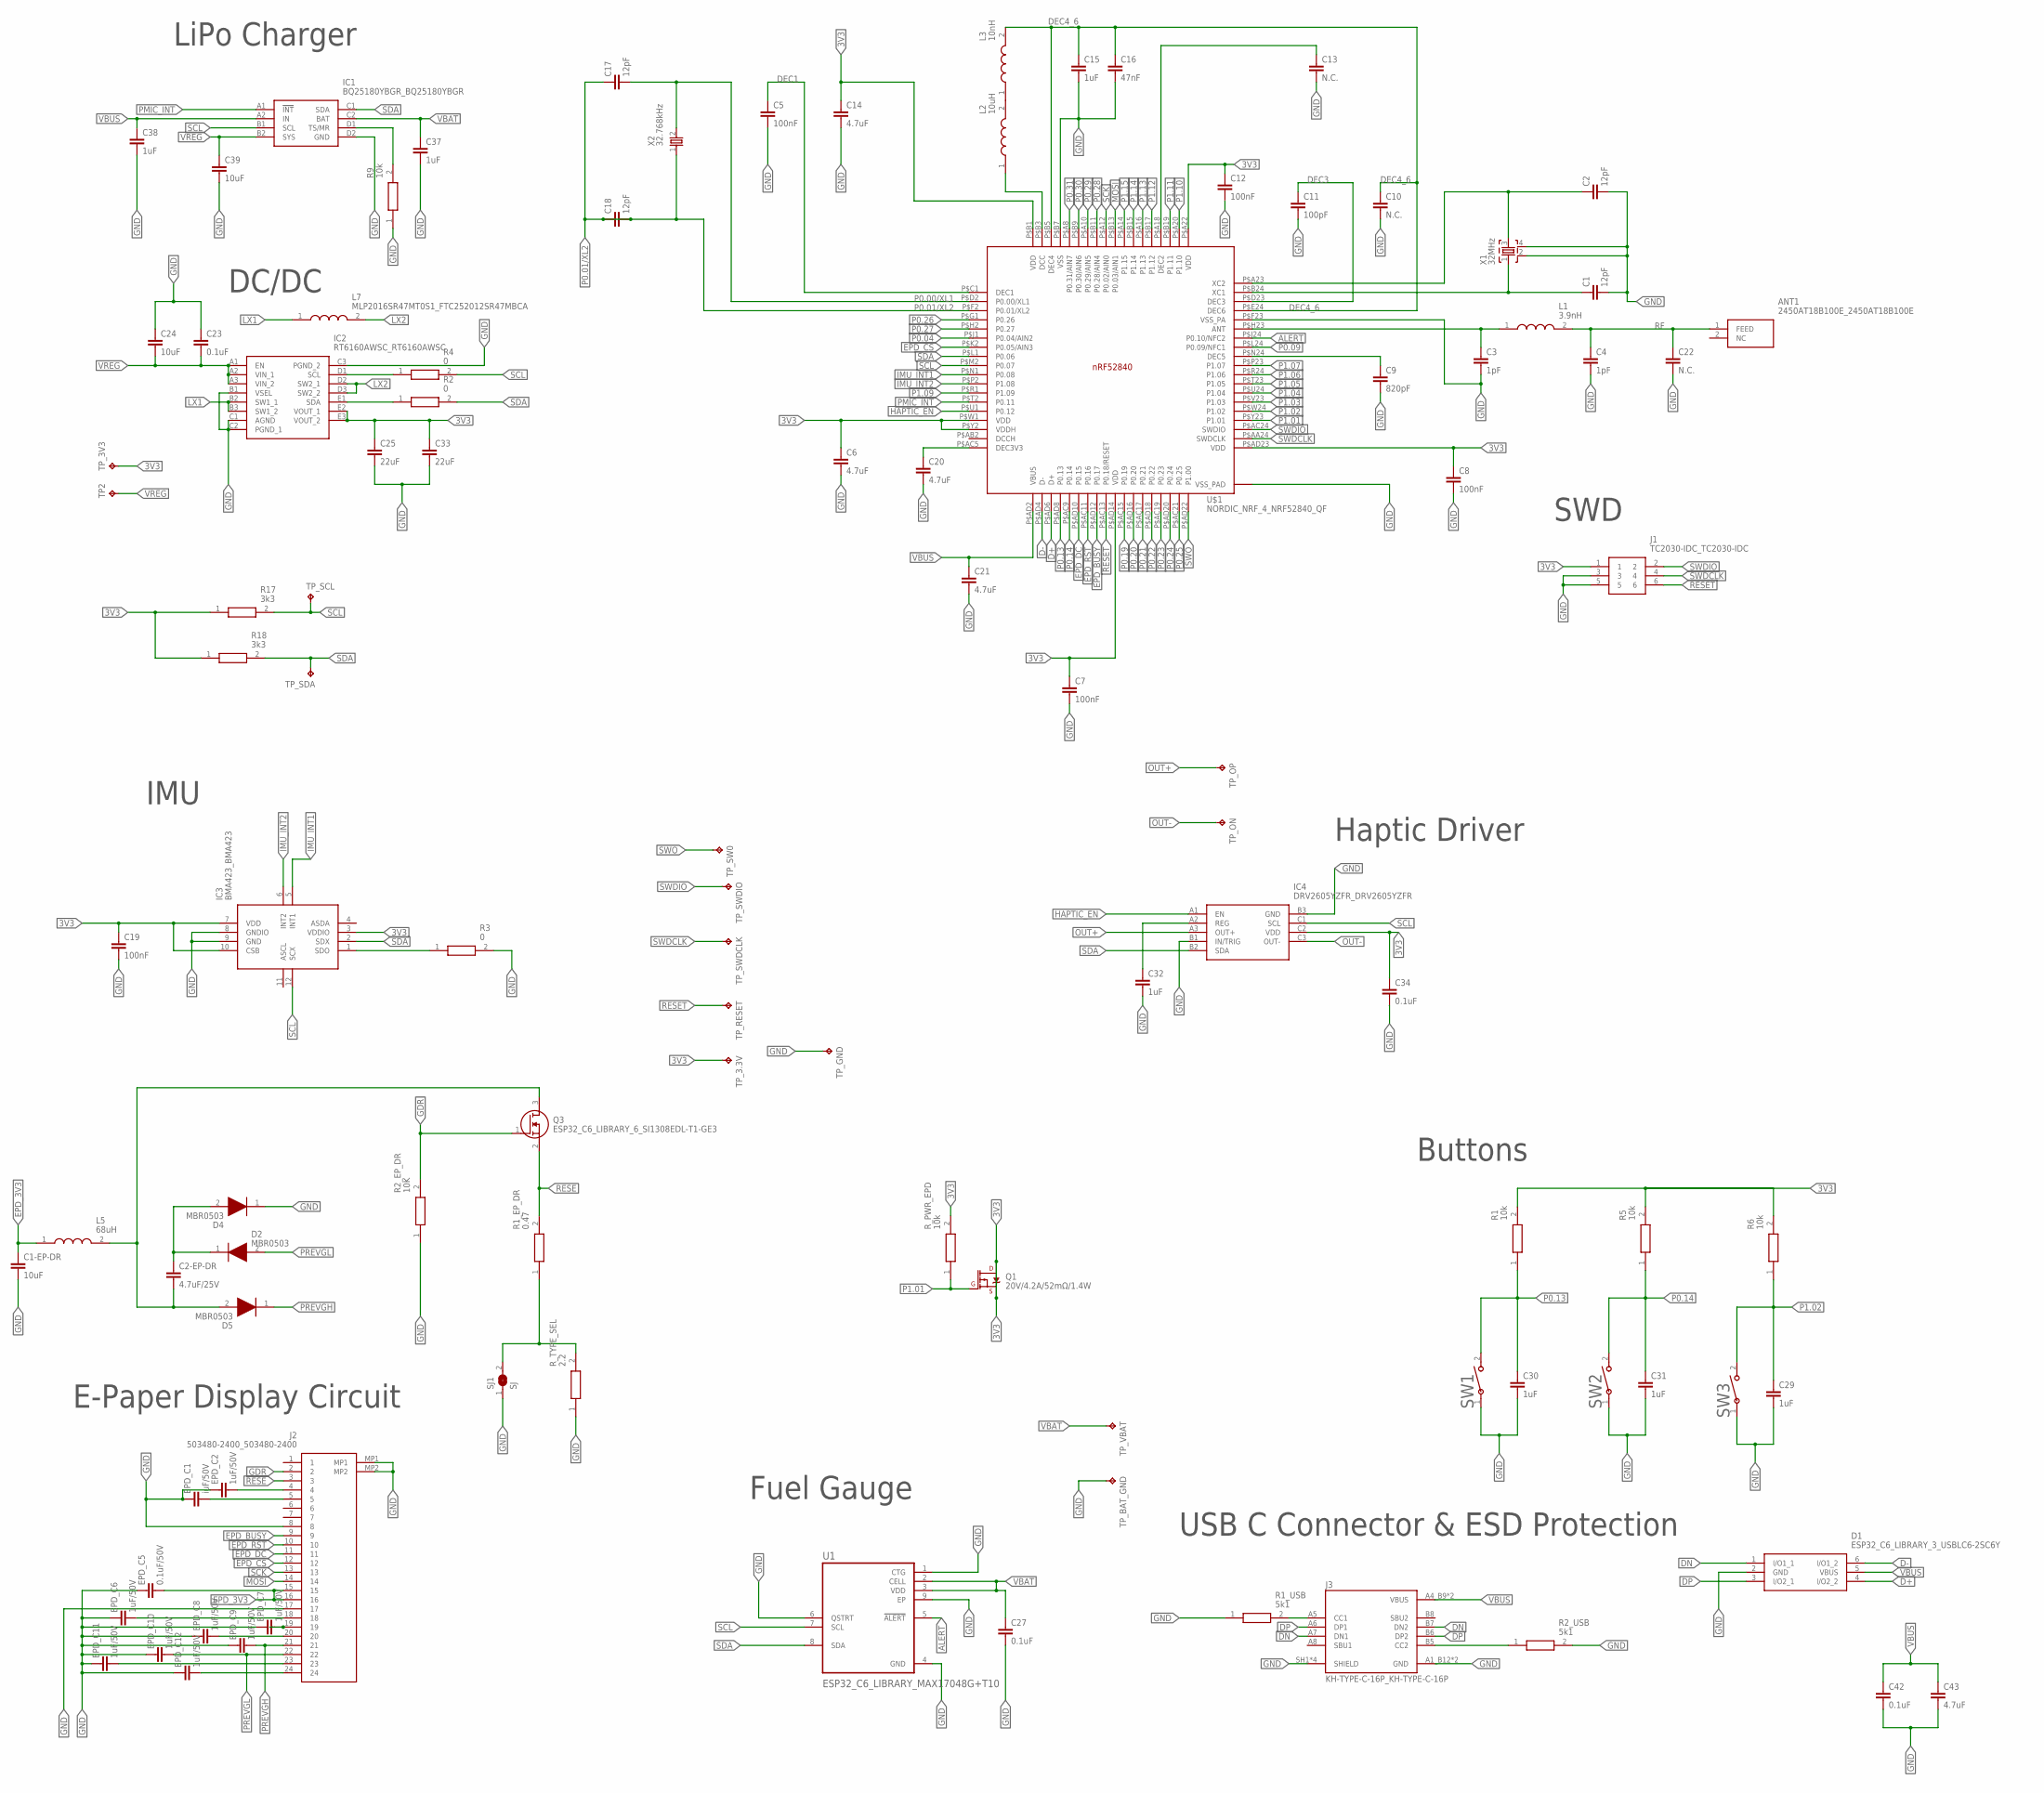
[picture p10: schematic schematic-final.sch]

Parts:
ANT1: 2450AT18B100E_2450AT18B100E; 2450AT18B100E_ANTC3216X140N
C1, C2, C17, C18: 12pF; ESP32_C6_LIBRARY_1_ESP32_WROVER_EAGLE-LTSPICE_C0402
C1-EP-DR, C24, C39: 10uF; ESP32_C6_LIBRARY_1_ESP32_WROVER_EAGLE-LTSPICE_C0402
C2-EP-DR: 4.7uF/25V; ESP32_C6_LIBRARY_1_ESP32_WROVER_EAGLE-LTSPICE_C0402
C3, C4: 1pF; ESP32_C6_LIBRARY_1_ESP32_WROVER_EAGLE-LTSPICE_C0402
C5, C7, C8, C12, C19: 100nF; NORDIC_NRF_3_RESC0201_L
C6, C14, C20, C21, C43: 4.7uF; ESP32_C6_LIBRARY_1_ESP32_WROVER_EAGLE-LTSPICE_C0402
C9: 820pF; ESP32_C6_LIBRARY_1_ESP32_WROVER_EAGLE-LTSPICE_C0402
C10, C13, C22: N.C.; ESP32_C6_LIBRARY_1_ESP32_WROVER_EAGLE-LTSPICE_C0402
C11: 100pF; ESP32_C6_LIBRARY_1_ESP32_WROVER_EAGLE-LTSPICE_C0402
C15, C29, C30, C31, C32, C37, C38: 1uF; ESP32_C6_LIBRARY_1_ESP32_WROVER_EAGLE-LTSPICE_C0402
C16: 47nF; ESP32_C6_LIBRARY_1_ESP32_WROVER_EAGLE-LTSPICE_C0402
C23, C27, C34, C42: 0.1uF; ESP32_C6_LIBRARY_1_ESP32_WROVER_EAGLE-LTSPICE_C0402
C25, C33: 22uF; ESP32_C6_LIBRARY_1_ESP32_WROVER_EAGLE-LTSPICE_C0402
D1: ESP32_C6_LIBRARY_3_USBLC6-2SC6Y; ESP32_C6_LIBRARY_3_SOT95P280X145-6N
D2, D4, D5: MBR0503; ESP32_C6_LIBRARY_5_SOD3716X135N
EPD_C1: iuF/50V; ESP32_C6_LIBRARY_1_ESP32_WROVER_EAGLE-LTSPICE_C0402
EPD_C2, EPD_C6, EPD_C7, EPD_C8, EPD_C9, EPD_C10, EPD_C11, EPD_C12: 1uF/50V; ESP32_C6_LIBRARY_1_ESP32_WROVER_EAGLE-LTSPICE_C0402
EPD_C5: 0.1uF/50V; ESP32_C6_LIBRARY_1_ESP32_WROVER_EAGLE-LTSPICE_C0402
IC1: BQ25180YBGR_BQ25180YBGR; BQ25180YBGR_BGA8C40P2X4_100X155X50
IC2: RT6160AWSC_RT6160AWSC; RT6160AWSC_BGA15C40P3X5_140X230X60
IC3: BMA423_BMA423
IC4: DRV2605YZFR_DRV2605YZFR; DRV2605YZFR_BGA9C50P3X3_144X144X62
J1: TC2030-IDC_TC2030-IDC; TC2030-IDC_TC2030IDC
J2: 503480-2400_503480-2400; 503480-2400_5034802400
J3: KH-TYPE-C-16P_KH-TYPE-C-16P; KH-TYPE-C-16P_KINGHELM_KH-TYPE-C-16P
L1: 3.9nH; MLP2016SR47MT0S1_INDC2016X100N
L2: 10uH; MLP2016SR47MT0S1_INDC2016X100N
L3: 10nH; MLP2016SR47MT0S1_INDC2016X100N
L5: 68uH; MLP2016SR47MT0S1_INDC2016X100N
L7: MLP2016SR47MT0S1_FTC252012SR47MBCA; MLP2016SR47MT0S1_INDC2016X100N
Q1: 20V/4.2A/52mΩ/1.4W; ESP32_C6_LIBRARY_4_ESP32_C6_LIBRARY_4_ESP32_C6_LIBRARY_4_ES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
Q3: ESP32_C6_LIBRARY_6_SI1308EDL-T1-GE3; ESP32_C6_LIBRARY_6_SOT65P210X110-3N
R1, R5, R6: 10k; ERA-1AEB3401C_0201
R1_EP_DR: 0.47; ERA-1AEB3401C_0201
R1_USB, R2_USB: 5k1; ERA-1AEB3401C_0201
R2, R3, R4: 0; ERA-1AEB3401C_0201
R2_EP_DR: 10K; ERA-1AEB3401C_0201
R9: 10k; CPF0201D7K68C1_0201
R17, R18: 3k3; ERA-1AEB3401C_0201
R_PWR_EPD: 10k; ERA-1AEB3401C_0201
R_TYPE_SEL: 2.2; ERA-1AEB3401C_0201
SJ1: SJ; ESP32_C6_LIBRARY_7_JUMPER_SJ
SW1, SW2, SW3: 2025-10-22_07-23-44_LIBRARY_EVP-AKE31ASW_EVP-AKE3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; 2025-10-22_07-23-44_LIBRARY_SW_EVP-AKE31A_PAN
TP2: HECTOR_WATCH_1_TPTP20R; HECTOR_WATCH_1_TP20R
TP_3.3V, TP_3V3: HECTOR_WATCH_1_TPTP20R; HECTOR_WATCH_1_TP20R
TP_BAT_GND: HECTOR_WATCH_1_TPTP20R; HECTOR_WATCH_1_TP20R
TP_GND: HECTOR_WATCH_1_TPTP20R; HECTOR_WATCH_1_TP20R
TP_ON: HECTOR_WATCH_1_TPTP20R; HECTOR_WATCH_1_TP20R
TP_OP: HECTOR_WATCH_1_TPTP20R; HECTOR_WATCH_1_TP20R
TP_RESET: HECTOR_WATCH_1_TPTP20R; HECTOR_WATCH_1_TP20R
TP_SCL: HECTOR_WATCH_1_TPTP20R; HECTOR_WATCH_1_TP20R
TP_SDA: HECTOR_WATCH_1_TPTP20R; HECTOR_WATCH_1_TP20R
TP_SW0: HECTOR_WATCH_1_TPTP20R; HECTOR_WATCH_1_TP20R
TP_SWDCLK: HECTOR_WATCH_1_TPTP20R; HECTOR_WATCH_1_TP20R
TP_SWDIO: HECTOR_WATCH_1_TPTP20R; HECTOR_WATCH_1_TP20R
TP_VBAT: HECTOR_WATCH_1_TPTP20R; HECTOR_WATCH_1_TP20R
U1: ESP32_C6_LIBRARY_MAX17048G+T10; ESP32_C6_LIBRARY_SON50P200X200X80-9N
U$1: NORDIC_NRF_4_NRF52840_QF; NORDIC_NRF_4_AQFN50P700X700X85_HS-74N
X1: 32MHz; NORDIC_NRF_BT-XTAL_2016_N
X2: 32.768kHz; NORDIC_NRF_1_XTAL_3215_N

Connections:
3V3: C6.1, C7.1, C8.1, C12.1, C14.1, C19.1, C25.1, C33.1, C34.1, IC2.E2 (VOUT_1), IC2.E3 (VOUT_2), IC3.3 (VDDIO), IC3.7 (VDD), IC3.10 (CSB), IC4.C2 (VDD), J1.1, Q1.2 (S), Q1.3 (D), R1.2, R5.2, R6.2, R17.1, R18.1, R_PWR_EPD.2, TP_3.3V.TP, TP_3V3.TP, U$1.P$A22 (VDD), U$1.P$AD14 (VDD), U$1.P$AD23 (VDD), U$1.P$B1 (VDD), U$1.P$W1 (VDD), U$1.P$Y2 (VDDH)
ALERT: U1.5 (!ALERT), U$1.P$J24 (P0.10/NFC2)
D+: D1.4 (I/O2_2), U$1.P$AD6 (D+)
D-: D1.6 (I/O1_2), U$1.P$AD4 (D-)
DEC1: C5.1, U$1.P$C1 (DEC1)
DEC3: C11.1, U$1.P$D23 (DEC3)
DEC4_6: C10.1, C15.1, C16.1, L3.2, U$1.P$B5 (DEC4), U$1.P$E24 (DEC6)
DN: D1.1 (I/O1_1), J3.A7 (DN1), J3.B7 (DN2)
DP: D1.3 (I/O2_1), J3.A6 (DP1), J3.B6 (DP2)
EPD_3V3: C1-EP-DR.1, EPD_C5.2, J2.15, J2.16, L5.1
EPD_BUSY: J2.9, U$1.P$AD12 (P0.17)
EPD_CS: J2.12, U$1.P$K2 (P0.05/AIN3)
EPD_DC: J2.11, U$1.P$AD10 (P0.15)
EPD_RST: J2.10, U$1.P$AC11 (P0.16)
GDR: J2.2, Q3.1 (G), R2_EP_DR.2
GND: C1.2, C1-EP-DR.2, C2.2, C3.2, C4.2, C5.2, C6.2, C7.2, C8.2, C9.2, C10.2, C11.2, C12.2, C13.2, C14.2, C15.2, C16.2, C19.2, C20.2, C21.2, C22.2, C23.1, C24.1, C25.2, C27.2, C29.2, C30.2, C31.2, C32.2, C33.2, C34.2, C37.2, C38.2, C39.2, C42.2, C43.2, D1.2 (GND), D4.1 (K), EPD_C1.1, EPD_C2.1, EPD_C5.1, EPD_C6.1, EPD_C7.1, EPD_C8.1, EPD_C9.1, EPD_C10.1, EPD_C11.1, EPD_C12.1, IC1.D2 (GND), IC2.B1 (VSEL), IC2.C1 (AGND), IC2.C2 (PGND_1), IC2.C3 (PGND_2), IC3.8 (GNDIO), IC3.9 (GND), IC4.B1 (IN/TRIG), IC4.B3 (GND), J1.3, J1.5, J2.8, J2.17, J2.MP1, J2.MP2, J3.A1_B12 (GND), J3.A12_B1 (GND), J3.SH1 (SHIELD), J3.SH2 (SHIELD), J3.SH3 (SHIELD), J3.SH4 (SHIELD), R1_USB.1, R2_EP_DR.1, R2_USB.2, R3.2, R9.1, R_TYPE_SEL.1, SJ1.1, SW1.1, SW2.1, SW3.1, TP_BAT_GND.TP, TP_GND.TP, U1.1 (CTG), U1.4 (GND), U1.6 (QSTRT), U1.9 (EP), U$1.P$74 (VSS_PAD), U$1.P$75 (VSS_PAD), U$1.P$76 (VSS_PAD), U$1.P$77 (VSS_PAD), U$1.P$78 (VSS_PAD), U$1.P$79 (VSS_PAD), U$1.P$80 (VSS_PAD), U$1.P$81 (VSS_PAD), U$1.P$82 (VSS_PAD), U$1.P$83 (VSS_PAD), U$1.P$84 (VSS_PAD), U$1.P$85 (VSS_PAD), U$1.P$86 (VSS_PAD), U$1.P$87 (VSS_PAD), U$1.P$88 (VSS_PAD), U$1.P$89 (VSS_PAD), U$1.P$90 (VSS_PAD), U$1.P$B7 (VSS), U$1.P$F23 (VSS_PA), X1.2, X1.4
HAPTIC_EN: IC4.A1 (EN), U$1.P$U1 (P0.12)
IMU_INT1: IC3.5 (INT1), U$1.P$N1 (P0.08)
IMU_INT2: IC3.6 (INT2), U$1.P$P2 (P1.08)
LX1: IC2.B2 (SW1_1), IC2.B3 (SW1_2), L7.1
LX2: IC2.D2 (SW2_1), IC2.D3 (SW2_2), L7.2
MOSI: J2.14, U$1.P$B13 (P0.03/AIN1)
unnamed: IC3.1 (SDO), R3.1
unnamed: IC2.D1 (SCL), R4.1
unnamed: IC1.D1 (TS/MR), R9.2
unnamed: IC2.E1 (SDA), R2.1
unnamed: C20.1, U$1.P$AC5 (DEC3V3)
unnamed: C9.1, U$1.P$N24 (DEC5)
unnamed: C3.1, L1.1, U$1.P$H23 (ANT)
unnamed: C13.1, U$1.P$A18 (DEC2)
unnamed: C2-EP-DR.2, D5.2 (A), L5.2, Q3.3 (D)
unnamed: L2.1, U$1.P$B3 (DCC)
unnamed: C2.1, U$1.P$A23 (XC2), X1.3
unnamed: C1.1, U$1.P$B24 (XC1), X1.1
unnamed: L2.2, L3.1
unnamed: R1_EP_DR.1, R_TYPE_SEL.2, SJ1.2
unnamed: C2-EP-DR.1, D2.1 (K), D4.2 (A)
unnamed: C32.1, IC4.A2 (REG)
unnamed: EPD_C2.2, J2.4
unnamed: EPD_C1.2, J2.5
unnamed: EPD_C6.2, J2.18
unnamed: EPD_C7.2, J2.19
unnamed: EPD_C8.2, J2.20
unnamed: EPD_C11.2, J2.23
unnamed: EPD_C12.2, J2.24
unnamed: J3.B5 (CC2), R2_USB.1
unnamed: J3.A5 (CC1), R1_USB.2
OUT+: IC4.A3 (OUT+), TP_OP.TP
OUT-: IC4.C3 (OUT-), TP_ON.TP
P0.00/XL1: C17.2, U$1.P$D2 (P0.00/XL1), X2.2
P0.01/XL2: C17.1, C18.1, C18.2, U$1.P$F2 (P0.01/XL2), X2.1
P0.04: U$1.P$J1 (P0.04/AIN2)
P0.09: U$1.P$L24 (P0.09/NFC1)
P0.13: C30.1, R1.1, SW1.2, U$1.P$AD8 (P0.13)
P0.14: C31.1, R5.1, SW2.2, U$1.P$AC9 (P0.14)
P0.19: U$1.P$AC15 (P0.19)
P0.20: U$1.P$AD16 (P0.20)
P0.21: U$1.P$AC17 (P0.21)
P0.22: U$1.P$AD18 (P0.22)
P0.23: U$1.P$AC19 (P0.23)
P0.24: U$1.P$AD20 (P0.24)
P0.25: U$1.P$AC21 (P0.25)
P0.26: U$1.P$G1 (P0.26)
P0.27: U$1.P$H2 (P0.27)
P0.28: U$1.P$B11 (P0.28/AIN4)
P0.29: U$1.P$A10 (P0.29/AIN5)
P0.30: U$1.P$B9 (P0.30/AIN6)
P0.31: U$1.P$A8 (P0.31/AIN7)
P1.01: Q1.1 (G), R_PWR_EPD.1, U$1.P$Y23 (P1.01)
P1.02: C29.1, R6.1, SW3.2, U$1.P$W24 (P1.02)
P1.03: U$1.P$V23 (P1.03)
P1.04: U$1.P$U24 (P1.04)
P1.05: U$1.P$T23 (P1.05)
P1.06: U$1.P$R24 (P1.06)
P1.07: U$1.P$P23 (P1.07)
P1.09: U$1.P$R1 (P1.09)
P1.10: U$1.P$A20 (P1.10)
P1.11: U$1.P$B19 (P1.11)
P1.12: U$1.P$B17 (P1.12)
P1.13: U$1.P$A16 (P1.13)
P1.14: U$1.P$B15 (P1.14)
P1.15: U$1.P$A14 (P1.15)
PMIC_INT: IC1.A1 (!INT), U$1.P$T2 (P0.11)
PREVGH: D5.1 (K), EPD_C9.2, J2.21
PREVGL: D2.2 (A), EPD_C10.2, J2.22
RESE: J2.3, Q3.2 (S), R1_EP_DR.2
RESET: J1.6, TP_RESET.TP, U$1.P$AC13 (P0.18/RESET)
RF: ANT1.1 (FEED), C4.1, C22.1, L1.2
SCK: J2.13, U$1.P$A12 (P0.02/AIN0)
SCL: IC1.B1 (SCL), IC3.12 (SCX), IC4.C1 (SCL), R4.2, R17.2, TP_SCL.TP, U1.7 (SCL), U$1.P$M2 (P0.07)
SDA: IC1.C1 (SDA), IC3.2 (SDX), IC4.B2 (SDA), R2.2, R18.2, TP_SDA.TP, U1.8 (SDA), U$1.P$L1 (P0.06)
SWDCLK: J1.4, TP_SWDCLK.TP, U$1.P$AC24 (SWDIO)
SWDIO: J1.2, TP_SWDIO.TP, U$1.P$AA24 (SWDCLK)
SWO: TP_SW0.TP, U$1.P$AD22 (P1.00)
VBAT: C27.1, C37.1, IC1.C2 (BAT), TP_VBAT.TP, U1.2 (CELL), U1.3 (VDD)
VBUS: C21.1, C38.1, C42.1, C43.1, D1.5 (VBUS), IC1.A2 (IN), J3.A4_B9 (VBUS), J3.A9_B4 (VBUS), U$1.P$AD2 (VBUS)
VREG: C23.2, C24.2, C39.1, IC1.B2 (SYS), IC2.A1 (EN), IC2.A2 (VIN_1), IC2.A3 (VIN_2), TP2.TP

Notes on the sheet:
LiPo Charger
DC/DC
IMU
SWD
Haptic Driver
E-Paper Display Circuit
Fuel Gauge
USB C Connector & ESD Protection
Buttons

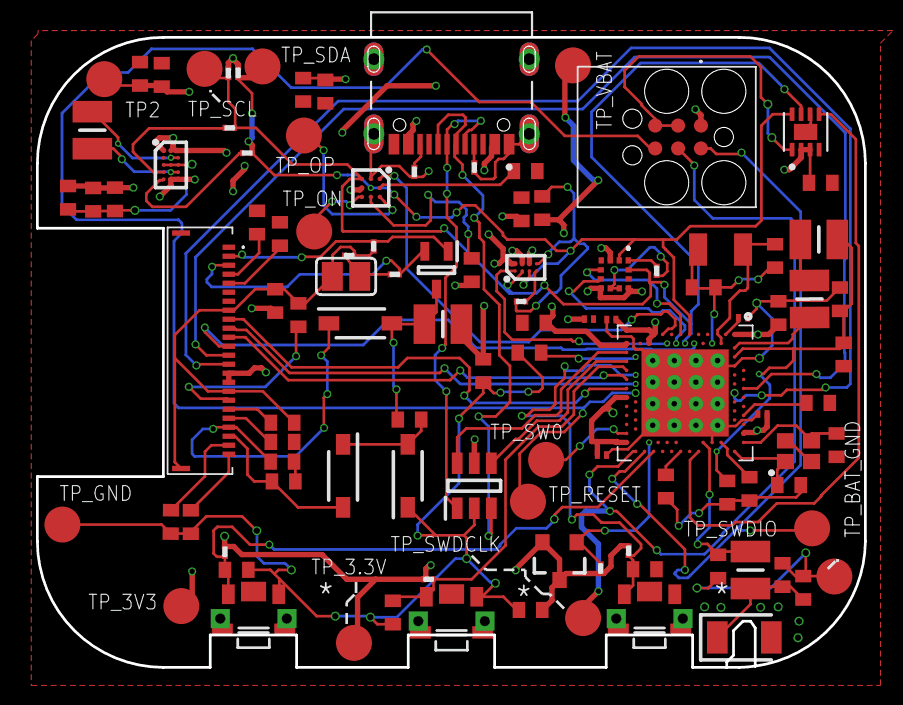
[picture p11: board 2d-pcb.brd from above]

Board: 4 copper layers, 46.0 x 35.0 mm, 105 parts (0 on the bottom side), 70 nets.

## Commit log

2026-04-16 added hw files in the right format
    [pcb-2d.brd, schematic.sch]
2026-04-16 added schematic printout
2026-04-16 added renders from bottom and side of pcb
2026-04-17 updated README with full bom
2026-04-17 updated schematic with labels
    [schematic-final.sch]
2026-04-21 added final 2d pcb version
    [2d-pcb.brd]

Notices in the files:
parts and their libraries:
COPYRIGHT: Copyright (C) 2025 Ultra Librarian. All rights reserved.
